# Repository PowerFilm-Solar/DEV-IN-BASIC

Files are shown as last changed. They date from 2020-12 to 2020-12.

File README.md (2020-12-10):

# DEV-IN-BASIC
Hardware files for PowerFilm's implementation of the BQ25570

The Indoor Solar Development Kit (DEV-IN-BASIC) makes integrating indoor solar into electronics simple. It consists of an energy harvesting module with integrated power management designed and optimized for Indoor Light Series solar panels.

The DEV-IN-BASIC kit uses a nano-power boost charging technology to efficiently extract energy from the indoor solar, even in dimly lit environments down to 200 lux and below. The integrated power management can be configured to store the collected energy into various storage element technologies. An output power rail is used to provide power to external electronics. 
 
### Development Kit Layout

![Indoor Solar Development Kit](https://www.powerfilmsolar.com/media/cms/products_dev_kits_devinbasic_diagra_45B16E6200140.jpg "
Indoor Solar Development Kit layout")

### What can I power?

- BLE Beacons and Tags
- E-Paper Displays
- Telematics
- Smart Locks
- Thermostats
- Smart Windows and Shades
- Wireless Sensors
- Wearables
- Field and Herd Monitoring
- Other Low Power Electronics

### Features

- Nano power DC-DC boost charger, with 100mV minimum input voltage.
- Integrated power management.
- Compatible with Li-ion, LiFePo, Thin-Film, capacitor, and supercapacitor rechargeable battery technologies.
- Adjustable battery under-voltage protection and load disconnect with hysteresis. 
- Adjustable battery overvoltage protection.
- Regulated output power rail with adjustable output voltage.
- All you need is a screwdriver to jump-start your idea into reality.

### Use Cases

- Designed for artificial lighting.
- Capable of powering low power wireless RF modules and sensors.
- Well suited for applications with intermittent high current pulsing common in most wireless protocol.
 
### What’s In The Kit?
##### Board

- DEV-IN-BASIC PCBA
##### Panel

- (2) LL200-3-37 Indoor Solar Panel with Leads
##### Battery 

- Model: DTP301120
- Nominal Voltage: 3.7V
- Typical Capacity: 40 mAh
- Includes protection circuit

No international shipments for online purchases. For delivery to other locations, please order via [Digi-Key](https://www.digikey.com/product-detail/en/powerfilm-inc/DEV-IN-BASIC/1996-DEV-IN-BASIC-ND/9695308) or [Mouser](https://www.mouser.com/ProductDetail/PowerFilm/DEV-IN-BASIC?qs=BJlw7L4Cy7%2Fw4dHFXPm5kg%3D%3D).
### Additional Resources

[Indoor Solar Development Kit Spec Sheet](https://www.powerfilmsolar.com/media/cms/Indoor_Solar_Development_Kit_LLDev1_083F9A3BC60A6.pdf)

[Indoor Solar Development Kit Flyer](https://www.powerfilmsolar.com/media/cms/Indoor_Solar_Development_Kit_Flyer_09CFAFE8ABEA2.pdf)

[Indoor Solar Development Kit Customization Guide](https://www.powerfilmsolar.com/media/cms/Indoor_Solar_Development_Kit_Custom_157741447633B.pdf)

[Indoor Solar Development Kit Design Files & Resources](https://www.powerfilmsolar.com/products/development-kits/indoor-solar-development-kit)

[IC (BQ25570) Data Sheet](http://www.ti.com/lit/ds/symlink/bq25570.pdf)

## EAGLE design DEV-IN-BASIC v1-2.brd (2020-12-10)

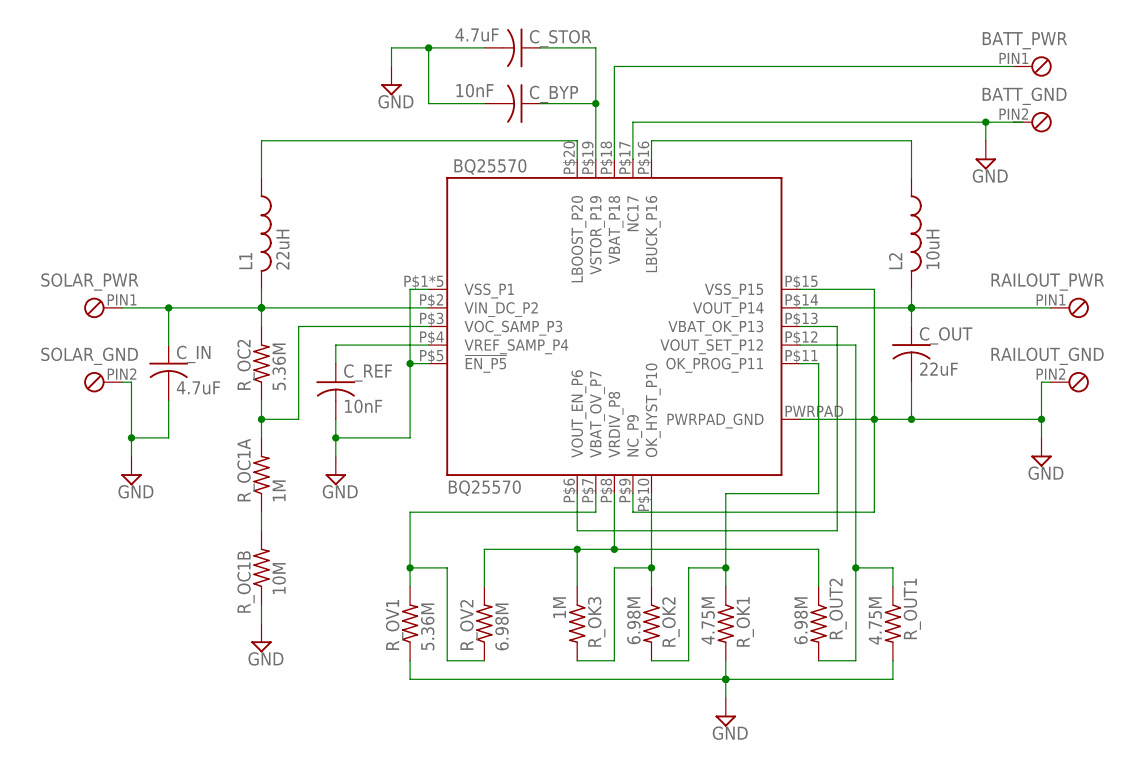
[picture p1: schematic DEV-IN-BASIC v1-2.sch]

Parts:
BATT_: TE_2PIN_CLARK; TE_CONN_2POS
BQ25570: BQ25570
C_BYP: 10nF; C0603; MFG_PART# CL10B103KB8SFNC
C_IN: 4.7uF; C0603; MFG_PART# CL10A475KQ8NNWC
C_OUT: 22uF; C0603; MFG_PART# GRM188R60J226MEA0D
C_REF: 10nF; C0603; MFG_PART# CL10B103KB8SFNC
C_STOR: 4.7uF; C0603; MFG_PART# CL10A475KQ8NNWC
L1: 22uH; 744031220
L2: 10uH; 744031220
RAILOUT_: TE_2PIN_CLARK; TE_CONN_2POS
R_OC1A: 1M; R0603; MFG_PART# RMCF0603FT1M00
R_OC1B: 10M; R0603; MFG_PART# RC0603FR-0710ML
R_OC2: 5.36M; R0603; MFG_PART# CRCW06035M36FKEA
R_OK1: 4.75M; R0603; MFG_PART# RC0603FR-074M75L
R_OK2: 6.98M; R0603; MFG_PART# CRCW06036M98FKEA
R_OK3: 1M; R0603; MFG_PART# RMCF0603FT1M00
R_OUT1: 4.75M; R0603; MFG_PART# RC0603FR-074M75L
R_OUT2: 6.98M; R0603; MFG_PART# CRCW06036M98FKEA
R_OV1: 5.36M; R0603; MFG_PART# CRCW06035M36FKEA
R_OV2: 6.98M; R0603; MFG_PART# CRCW06036M98FKEA
SOLAR_: TE_2PIN_CLARK; TE_CONN_2POS

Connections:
GND: BATT_.PIN2, BQ25570.P$1 (VSS_P1), BQ25570.P$5 (!EN_P5), BQ25570.P$9 (NC_P9), BQ25570.P$15 (VSS_P15), BQ25570.P$17 (NC17), BQ25570.P$21 (VSS_P1), BQ25570.P$22 (VSS_P1), BQ25570.P$23 (VSS_P1), BQ25570.P$24 (VSS_P1), BQ25570.PWRPAD (PWRPAD_GND), C_BYP.2, C_IN.2, C_OUT.2, C_REF.2, C_STOR.2, RAILOUT_.PIN2, R_OC1B.1, R_OK1.2, R_OUT1.2, R_OV1.1, SOLAR_.PIN2
LBOOST_PIN20: BQ25570.P$20 (LBOOST_P20), L1.PIN1 (1)
LBUCK_PIN16: BQ25570.P$16 (LBUCK_P16), L2.PIN1 (1)
unnamed: R_OC1A.1, R_OC1B.2
OK_HYST_PIN10: BQ25570.P$10 (OK_HYST_P10), R_OK2.1, R_OK3.2
OK_PROG_PIN11: BQ25570.P$11 (OK_PROG_P11), R_OK1.1, R_OK2.2
RAILOUT_POS: BQ25570.P$14 (VOUT_P14), C_OUT.1, L2.PIN2 (2), RAILOUT_.PIN1
SOLAR_PWR_VIN: BQ25570.P$2 (VIN_DC_P2), C_IN.1, L1.PIN2 (2), R_OC2.2, SOLAR_.PIN1
VBAT: BATT_.PIN1, BQ25570.P$18 (VBAT_P18)
VBAT_OK: BQ25570.P$6 (VOUT_EN_P6), BQ25570.P$13 (VBAT_OK_P13)
VBAT_OV_PIN7: BQ25570.P$7 (VBAT_OV_P7), R_OV1.2, R_OV2.1
VOC_SAMP_PIN3: BQ25570.P$3 (VOC_SAMP_P3), R_OC1A.2, R_OC2.1
VOUT_SET_PIN12: BQ25570.P$12 (VOUT_SET_P12), R_OUT1.1, R_OUT2.2
VRDIV_PIN8: BQ25570.P$8 (VRDIV_P8), R_OK3.1, R_OUT2.1, R_OV2.2
VREF_SAMP_PIN4: BQ25570.P$4 (VREF_SAMP_P4), C_REF.1
VSTOR: BQ25570.P$19 (VSTOR_P19), C_BYP.1, C_STOR.1

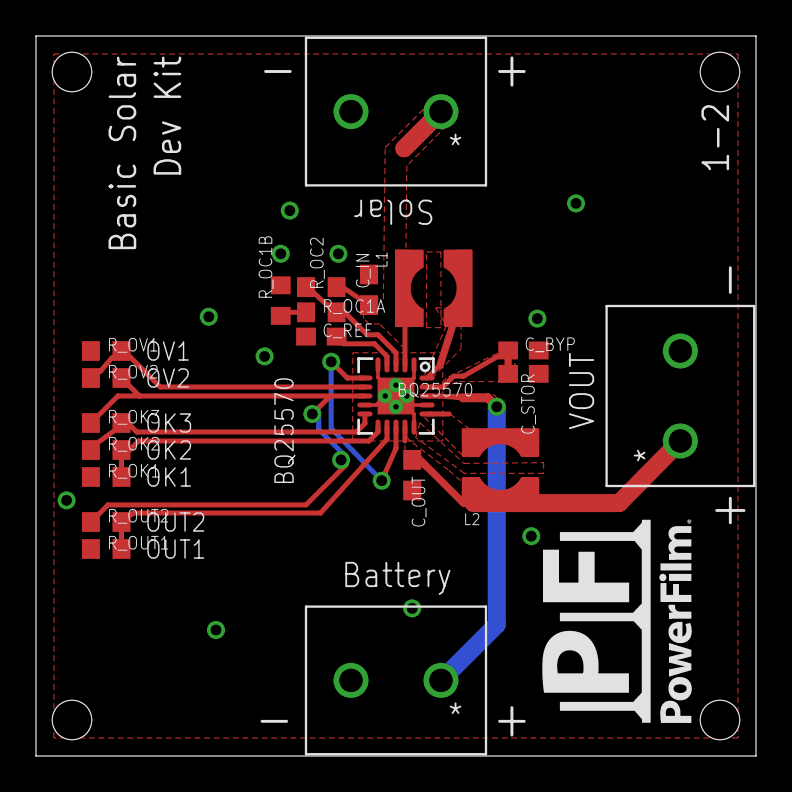
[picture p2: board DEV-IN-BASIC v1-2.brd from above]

Board: 2 copper layers, 40.0 x 40.0 mm, 21 parts (0 on the bottom side), 16 nets.

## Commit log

2020-12-10 Added libraries
    [DEV-IN-BASIC v1-2.brd, DEV-IN-BASIC v1-2.sch]
2020-12-10 Fixed unrouted trace
    [DEV-IN-BASIC v1-2.brd]
